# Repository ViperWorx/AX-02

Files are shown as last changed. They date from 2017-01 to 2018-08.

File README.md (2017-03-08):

<h1>AX-02 Delta 3D Printer</h1>

This is a ground up design of a Delta Kinematic based 3D Printer. The ethos of this printer is to keep costs as low as possible but have a rock solid frame as a base with a large print area.

Usable print area is 300mm diameter with a Z Height of around 200mm. The printer is Smoothieware based using the [Azteeg X5 mini](http://www.panucatt.com/azteeg_X5_mini_reprap_3d_printer_controller_p/ax5mini.htm) by Panucatt Devices, 24 volt electronics with a 230v heated bed

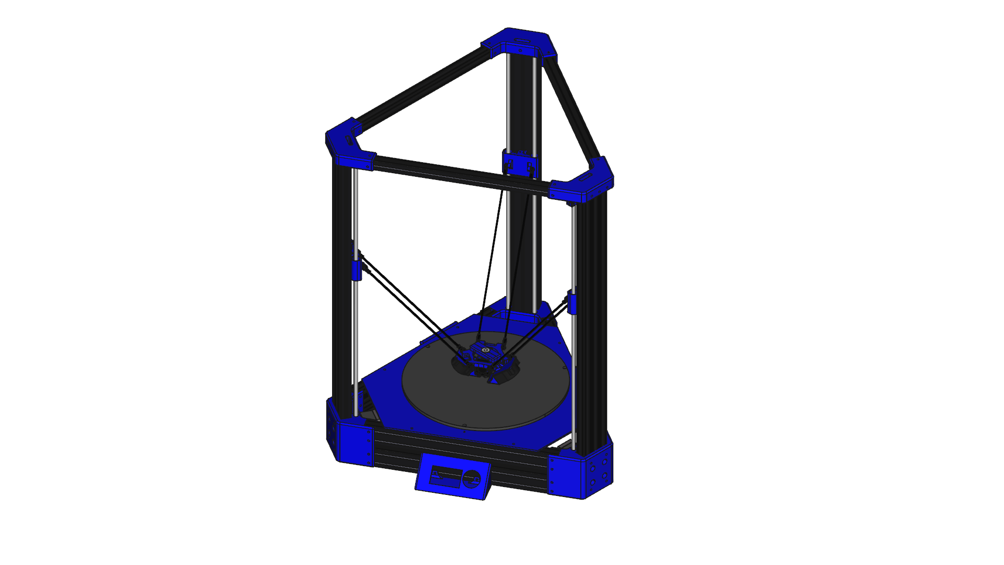
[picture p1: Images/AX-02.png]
 

<hr />
<table border="0px">
<th align="left">
&copy; AxMod 3D Print 2017.
</th>
<tr>
<td>
This documentation describes Open Hardware and is licensed under the CERN OHL v. 1.2.
</td>
</tr>
<tr>
<td>
You may redistribute and modify this documentation under the terms of the
CERN OHL v.1.2. (http://ohwr.org/cernohl). This documentation is distributed
WITHOUT ANY EXPRESS OR IMPLIED WARRANTY, INCLUDING OF
MERCHANTABILITY, SATISFACTORY QUALITY AND FITNESS FOR A
PARTICULAR PURPOSE. Please see the CERN OHL v.1.2 for applicable
conditions
</td>
</tr>
</table>

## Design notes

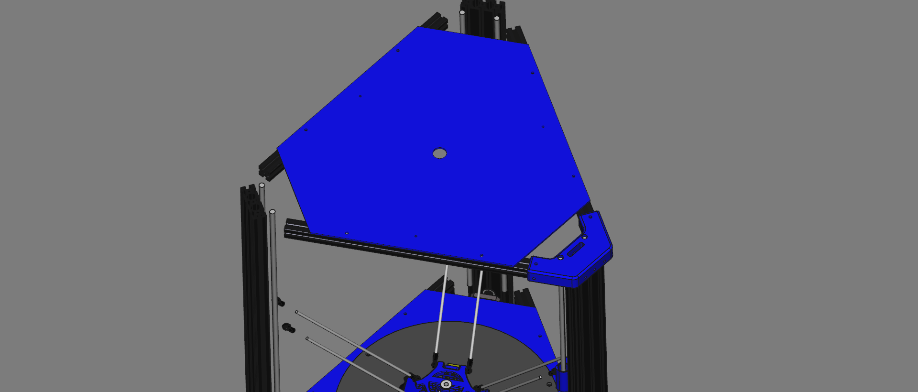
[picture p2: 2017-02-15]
Images/AX-02_5.png

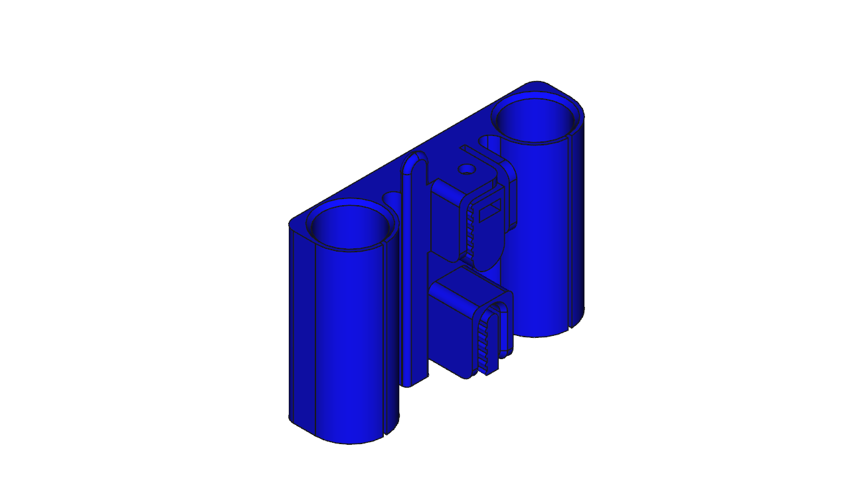
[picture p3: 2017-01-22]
Images/AX-02_3.png

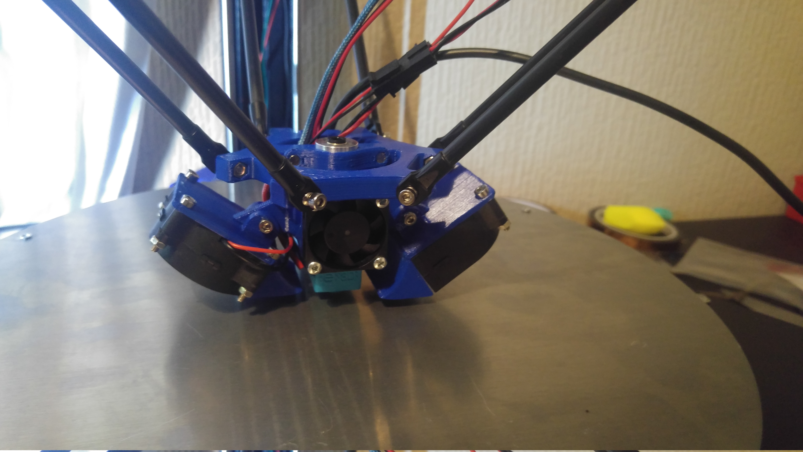
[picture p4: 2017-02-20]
Images/20170220_183212_HDR.jpg

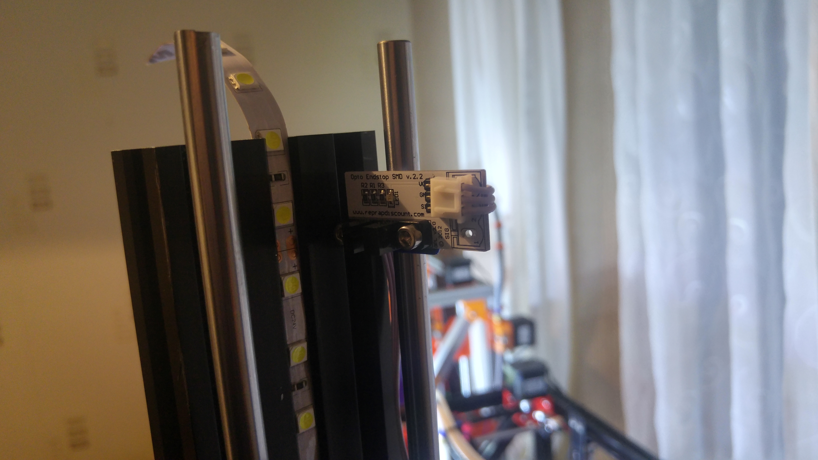
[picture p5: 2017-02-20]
Images/20170220_184052_HDR.jpg

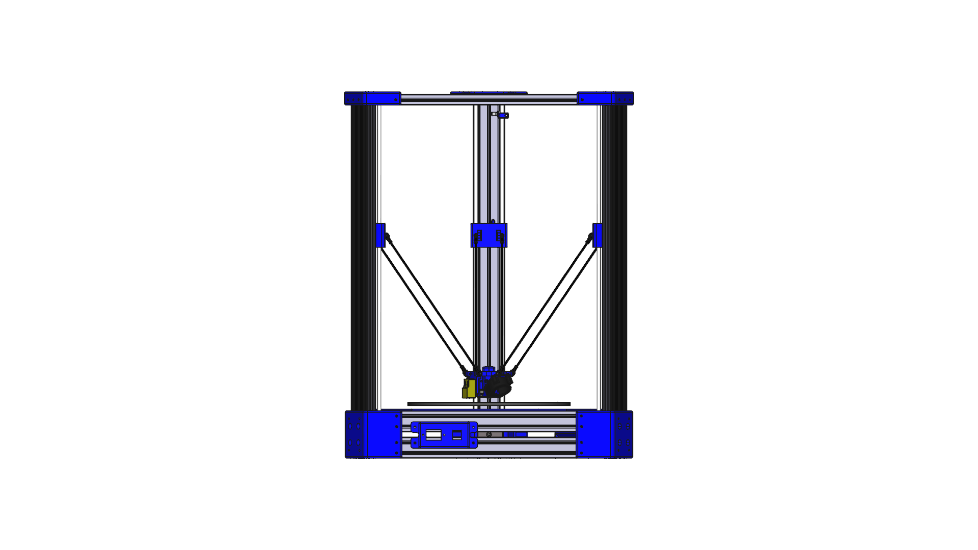
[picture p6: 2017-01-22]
Images/AX-02_1.png

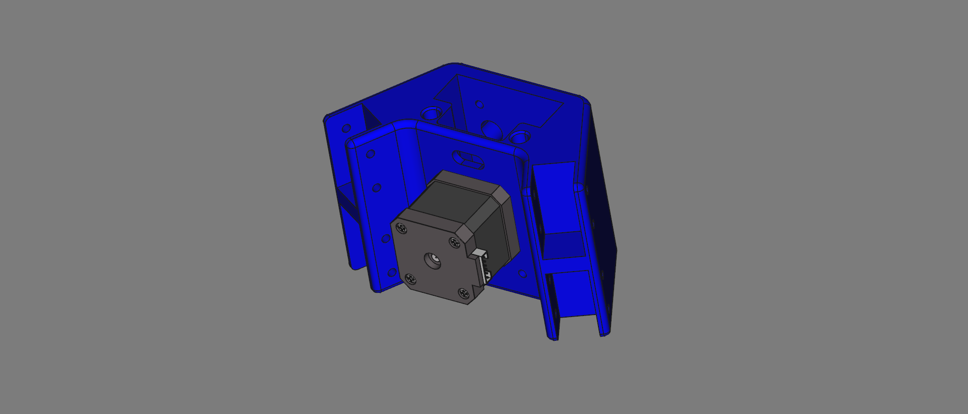
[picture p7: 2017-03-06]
Images/AX-02_6.png

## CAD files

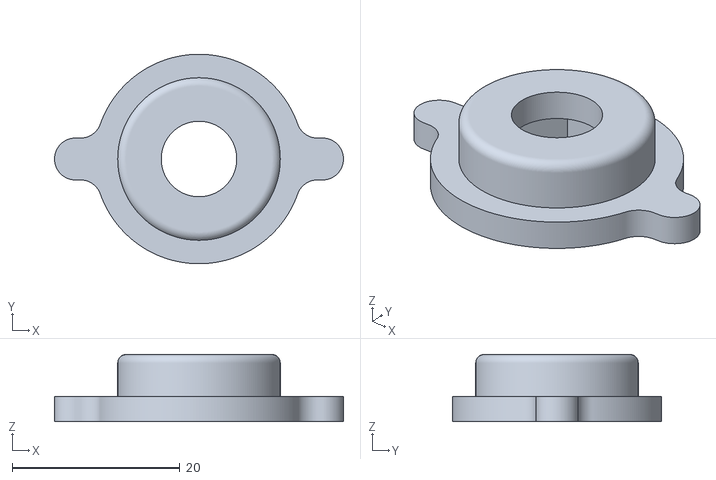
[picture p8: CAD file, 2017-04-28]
1_Spool_Holder_Bottom_Clamp.stl
34.5 x 25.0 x 8.00

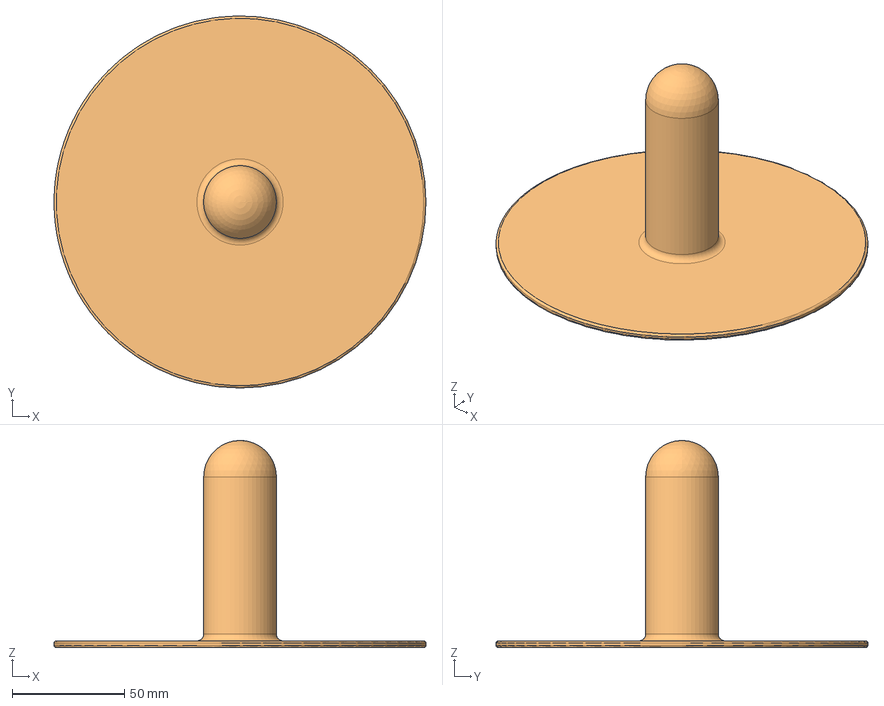
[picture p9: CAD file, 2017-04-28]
FreeCAD/Spool Holder.fcstd
165.6 x 165.6 x 92.2 mm

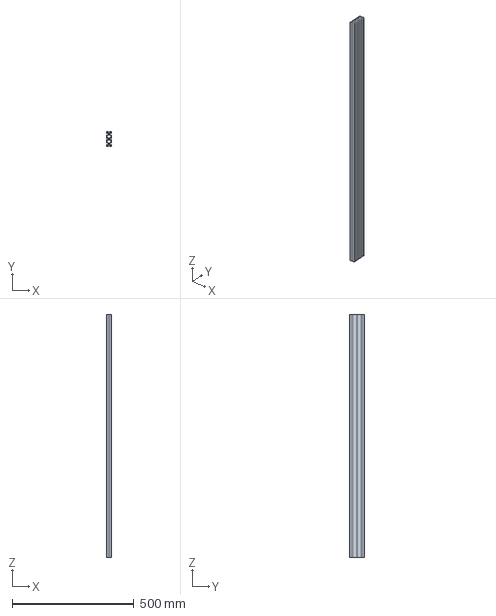
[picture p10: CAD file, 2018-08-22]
FreeCAD/STEP/Hardware Parts/NFS5-2060-1000.stp
20.0 x 60.0 x 1000.0 mm

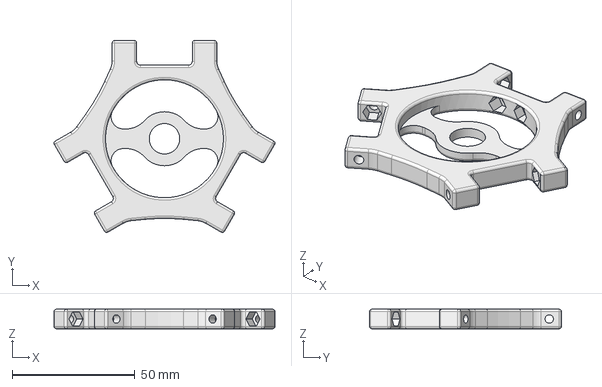
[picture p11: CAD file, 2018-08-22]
FreeCAD/STEP/Printed Parts/Effector_E3D_New.step
89.9 x 78.2 x 8.00 mm

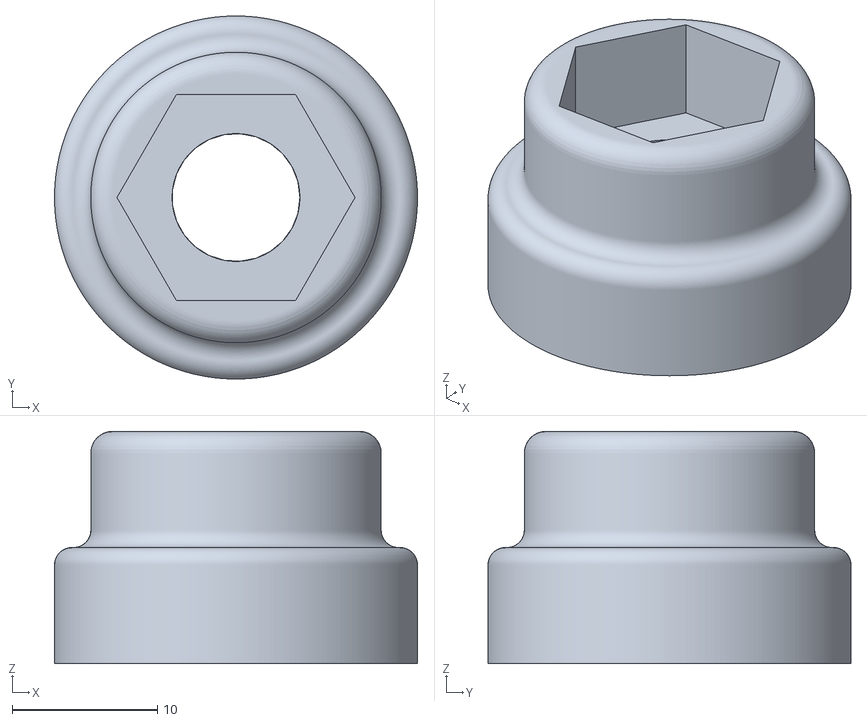
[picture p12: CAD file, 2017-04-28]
1_Spool_Holder_Top_Clamp.stl
25.0 x 25.0 x 16.0

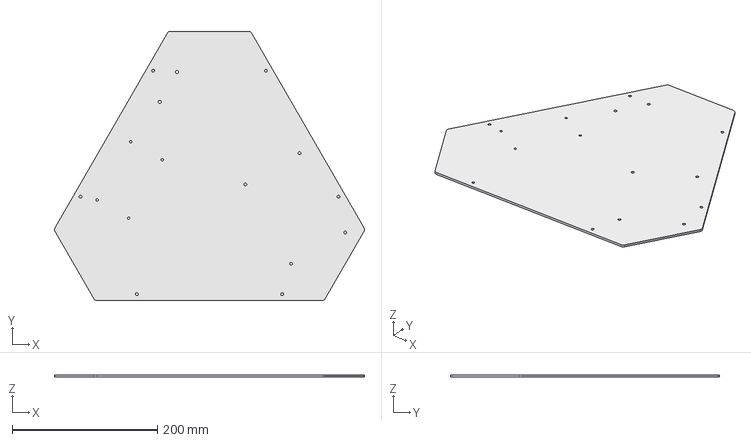
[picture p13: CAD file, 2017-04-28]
FreeCAD/Plates.fcstd
426.4 x 370.7 x 3.00 mm

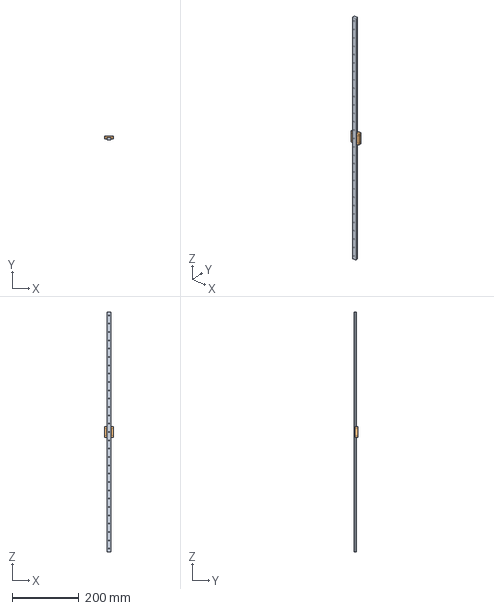
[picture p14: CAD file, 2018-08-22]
FreeCAD/STEP/Hardware Parts/SSEB13-720.stp
27.0 x 13.0 x 720.0 mm
_SSEB13-720_r
_SSEB13_b

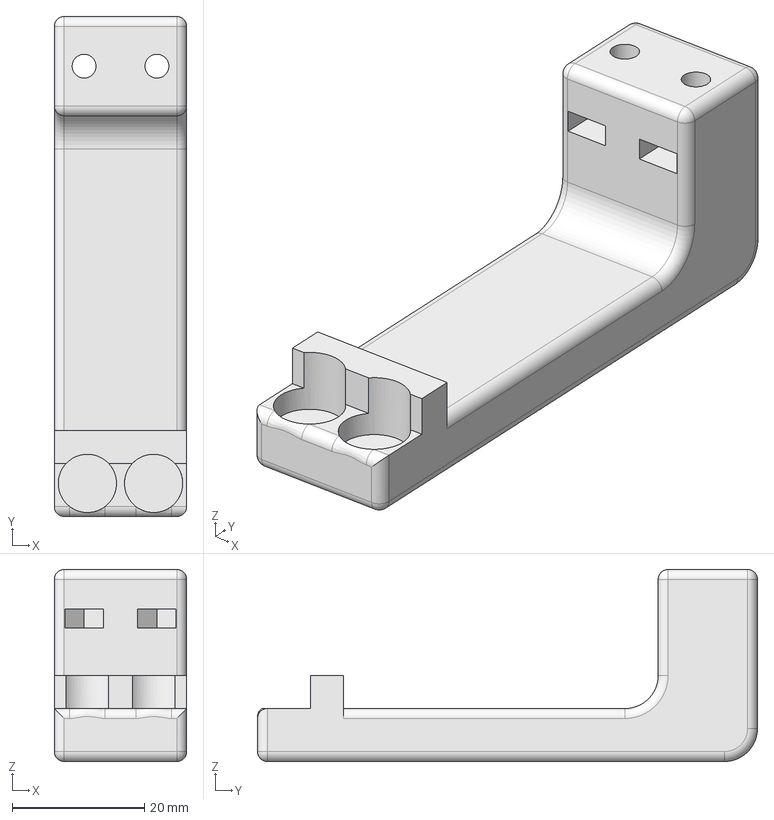
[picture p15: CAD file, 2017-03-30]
FreeCAD/STEP/Printed Parts/Sensor_Mount.step
20.0 x 75.5 x 29.0 mm

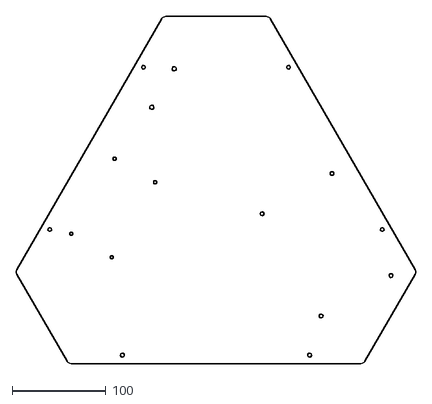
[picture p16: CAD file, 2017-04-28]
Electronics_Plate.dxf
426.9 x 370.7

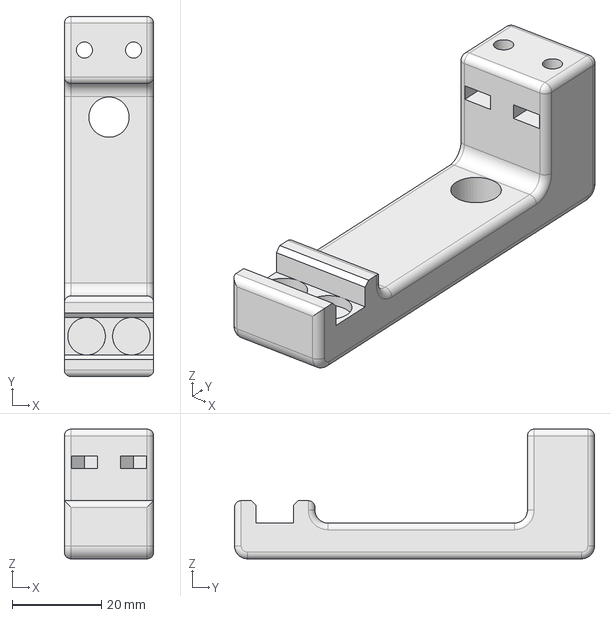
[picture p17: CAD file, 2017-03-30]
FreeCAD/Sensor_Mount.fcstd
20.0 x 80.5 x 29.0 mm

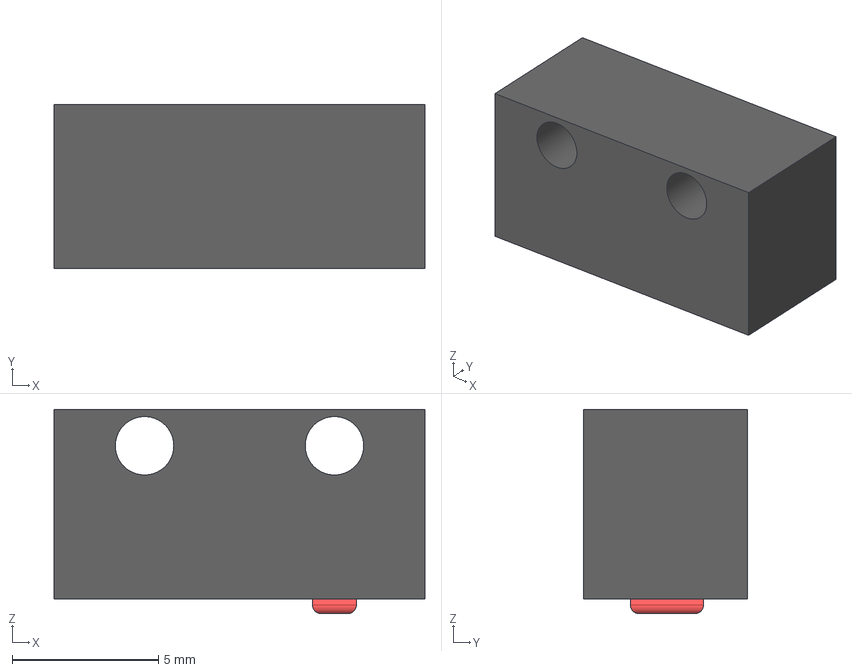
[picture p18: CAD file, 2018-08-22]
FreeCAD/STEP/Hardware Parts/Sub_Micro_Switch_No_Lever.step
12.7 x 5.60 x 7.00 mm
Button

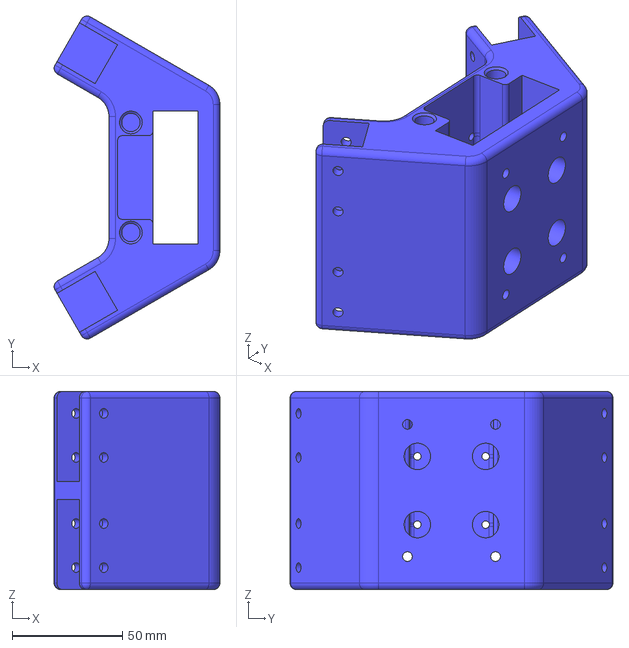
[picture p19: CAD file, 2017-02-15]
FreeCAD/STEP/Printed Parts/Bottom_Bracket.step
75.3 x 146.7 x 90.0 mm

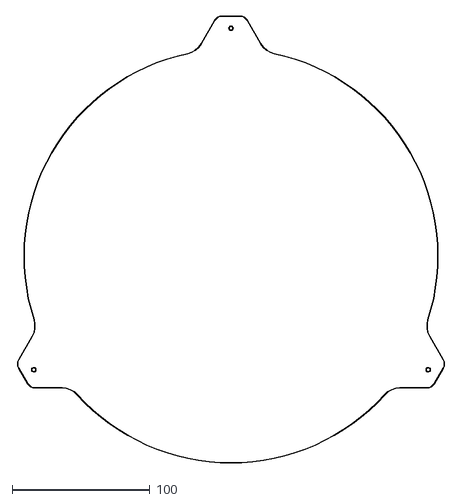
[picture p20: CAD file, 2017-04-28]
Build_Plate.dxf
311.6 x 323.9

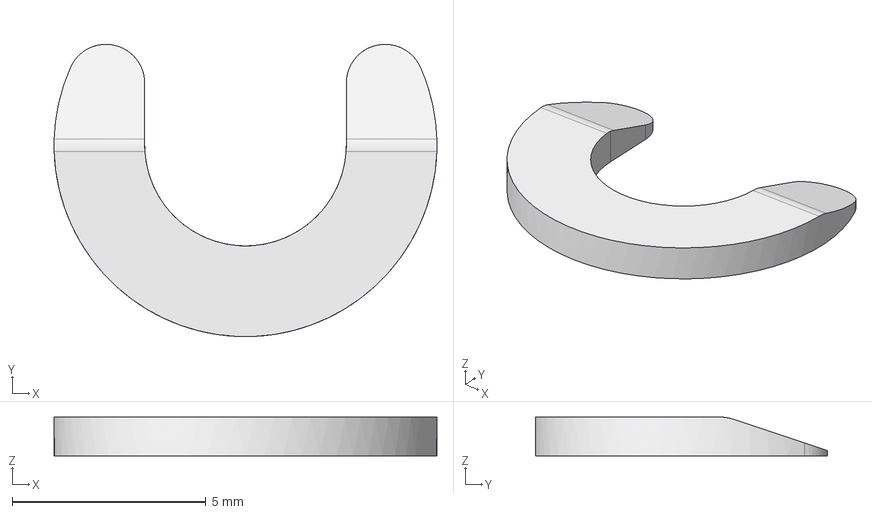
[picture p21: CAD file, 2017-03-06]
FreeCAD/Bowden_Clip.fcstd
9.88 x 7.54 x 1.00 mm

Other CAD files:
FreeCAD/STEP/Hardware Parts/Build_plate.step
FreeCAD/STEP/Printed Parts/Top_Bracket.step
Cover_Plate.dxf
FreeCAD/Arm_Tensioner.fcstd
1_Bowden_Clip.stl
1_Dual_30mm_Fan_Bracket-Board_Cooler.stl
1_Effector.stl
1_Hot_End_Clamp.stl
1_Hot_End_Fan_Housing.stl
1_IEC_Ethernet_USB_Case.stl
1_Mini_Viki_Case_Base.stl
1_Mini_Viki_Case_Front.stl
1_Mini_Viki_Case_Front_Logo.stl
1_Mini_Viki_Case_Front_Logo_Cutout.stl
1_Sensor_Mount.stl
2_Layer_Fan Mount.stl
3_Arm_Tensioner.stl
3_Belt_Tensioner.stl
3_Bottom_Bracket.stl
3_Carriage.stl
3_Endstop_Mount.stl
3_Top_Bracket.stl
6_11mm_Wire_Bundle_Clip.stl
6_8mm_Bushing_Print_In_Nylon.stl
6_Electronics_Plate_Bracket.stl
8_Bowden_Tube_Wire_Bundle_Clip.stl
AX-02_Logo.dxf
FreeCAD/8mm_Bush.fcstd
FreeCAD/AX-02_Logo_3D.fcstd
FreeCAD/Bowden_Tube_ Wire_Bundle_Clip.fcstd
FreeCAD/Dual_30mm_Fan Bracket.fcstd
FreeCAD/Electronics_Plate_Bracket.fcstd
FreeCAD/IEC case.fcstd
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

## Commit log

2017-01-15 Initial File Commit
    [26054-03.stp, 30mm Fan.step, 40mm_fan.stp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]
2017-01-17 Update CAD
    [Optical endstop v3.step, SN04-N.STEP]
2017-01-17 Add STL Files for Printing
    [1_Effector.stl, 1_Hot_End_Clamp.stl, 1_Hot_End_Fan_Housing.stl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]
2017-01-22 Update Top Bracket to use 7mm width idlers over 625ZZ bearings
    [3_Top_Bracket.stl]
2017-01-22 Adding Drawing of Build Plate for cutting
    [Build Plate.dxf]
2017-01-22 Update Carriage to add belt tensioning system
    [1_Belt_Tensioner.stl, 3_Carriage.stl]
2017-01-22 CAD Updated to reflect changes
2017-01-22 Update CAD and clean up model
2017-01-22 Mounting case for IEC Mains socket and Ethernet Coupler
    [1_IEC_Ethernet_Case.stl, IEC case.fcstd]
2017-01-22 Add Mini Viki Case
    [1_Mini_Viki_Case_Base.stl, 1_Mini_Viki_Case_Front.stl, Mini Viki Screen Mount.fcstd]
2017-01-22 Add DXF for laser cutting of Acrylic cover
    [Acrylic_Cover.dxf]
2017-01-22 Step files of Printed parts to clean up CAD
    [Bottom_Bracket.step, Carriage.step, Endstop_mount.step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]
2017-01-22 File Structure tidy
    [26054-03.stp, 30mm Fan.step, 40mm_fan.stp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]
2017-01-22 Add Schlotzz Extruder
    http://www.thingiverse.com/thing:275593
    [1_Compact_Direct_Drive_Extruder_Idler.stl, 1_Compact_Direct_Drive_Extruder_M4.stl]
2017-01-22 Add Spool Hanger
    [1_Spool_Hanger.stl, Spool_Hanger.fcstd]
2017-01-25 Adding Printed Tools - Rotary Tool Delta Arm Cutting Jig
    Cut arms accurately with a rotary tool
    [Arm Cutting Jig.fcstd, Jig_Arm.stl, Jig_Arm_Clamp.stl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]
2017-01-26 Moving fan mount holes to correct position and adding anti warp support
    [2_Layer_Fan Mount.stl, Layer_Fan.step]
2017-01-26 CAD Update
2017-01-26 Fix fan hole postion and add anti-warp support
    [2_Layer_Fan Mount.stl, Layer_Fan.step]
2017-01-27 Correcting mounting holes in Layer fan mount
    [2_Layer_Fan Mount.stl, Layer_Fan+Mount.step, Layer_Fan_Mount.step]
2017-01-27 New design Effector and Hot End Clamping system
    [1_Effector.stl, 1_Hot_End_Clamp.stl]
2017-01-27 CAD Updated to match recent changers
    Arms are now the correct length, new effector, new hot end clamping system, layer fan mounting holes corrected.
2017-01-27 Orientating parts for printing.
    [1_Belt_Tensioner.stl, 1_Effector.stl, 1_Hot_End_Clamp.stl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]
2017-01-29 Remove fan cut out on effector - no longer needed.
    [1_Effector.stl]
2017-01-30 Increase Bed Plate by 10mm
    [Build Plate.dxf]
2017-01-31 Update Layer Fan and Hot end fan mounts
    [1_Hot_End_Fan_Housing.stl, 2_Layer_Fan Mount.stl, Layer_Fan_Mount.step]
2017-02-03 Missed Layer Fan mount from previous commit
    [2_Layer_Fan Mount.stl]
2017-02-03 Correcting Mini Viki placement in mount
    [1_Mini_Viki_Case_Base.stl, 1_Mini_Viki_Case_Front.stl, Mini Viki Screen Mount.fcstd]
2017-02-03 Add 1mm to Hot end mount
    [1_Effector.stl, 1_Hot_End_Clamp.stl]
2017-02-03 Correct mounting screen points and add logo to case (dual extrusion)
    [1_Mini_Viki_Case_Front.stl, 1_Mini_Viki_Case_Front_Logo.stl, 1_Mini_Viki_Case_Front_Logo_Cutout.stl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]
2017-02-04 Tighten up Groove Mount for Hot End
    [1_Effector.stl, 1_Hot_End_Clamp.stl]
2017-02-05 Changing number to print
    [1_Belt_Tensioner.stl, 3_Belt_Tensioner.stl]
2017-02-05 Modified so rods can be slid into place
    [3_Top_Bracket.stl]
2017-02-05 Tolerances on Groove mount tightened up
    [1_Hot_End_Clamp.stl]
2017-02-05 CAD File updated with changes
2017-02-05 Correct error with Belt tensioning system
    [3_Belt_Tensioner.stl, 3_Carriage.stl]
2017-02-05 Reduce Endstop mounting pad by 1.5mm
    Allow for belt path
    [3_Endstop_Mount.stl]
2017-02-05 Main CAD File updated to reflect changes
2017-02-06 Re-work GT2 belt tensioner
    [3_Belt_Tensioner.stl, 3_Carriage.stl]
2017-02-08 IEC case.. now with added USB hole..
    [1_IEC_Ethernet_Case.stl, 1_IEC_Ethernet_USB_Case.stl, IEC case.fcstd]
2017-02-09 Add Acrylic Electronics mounting plate
    [Electronics_Plate.dxf]
2017-02-15 Add 8mm Bushings to be printed in Nylon
    [6_8mm_Bushing_Print_In_Nylon.stl, 8mm_Bush.fcstd]
2017-02-15 Add extra STEP files for modelling
    [2020_1.step, 2040_1.obj, 2040_1.step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]
2017-02-15 Update main CAD
2017-02-15 Add .gitignore - remove tools as design did not work well
    [Arm Cutting Jig.fcstd, Jig_Arm.stl, Jig_Arm_Clamp.stl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]
2017-02-20 Enlarge idler hole
    [3_Top_Bracket.stl]
2017-02-20 Add Cover Step file
    [Cover.step]
2017-02-21 Add wire routing hole
    [3_Bottom_Bracket.stl]
2017-02-21 Enlarge rod holes
    [3_Top_Bracket.stl]
2017-02-21 CAD Updated with latest changes
2017-02-23 Adding material to carraige to prevent snapping
    [3_Carriage.stl]
2017-02-23 Adding Active Board cooling bracket
    [1_Dual_30mm_Fan_Bracket-Board_Cooler.stl, Dual_30mm_Fan Bracket.fcstd]
2017-02-25 Wire Management parts added
    [Bowden_Tube_ Wire_Bundle_Clip.fcstd, Wire_Bundle_Clip.fcstd]
2017-03-06 Add Electronics Plate Bracket
    [6_Electronics_Plate_Bracket.stl, Electronics_Plate_Bracket.fcstd]
2017-03-06 Add Arm Tensioners
    [3_Arm_Tensioner.stl, Arm_Tensioner.fcstd]
2017-03-06 Main CAD Update
2017-03-06 Modify hole Position in electronics plate
    [Electronics_Cover.step, Electronics_Plate.dxf]
2017-03-06 Add Bowden Clip
    [1_Bowden_Clip.stl, Bowden_Clip.fcstd]
2017-03-06 Add Bottom Corner render - added wire channel
2017-03-14 Remove Schlotzz Extruder - Add Drakon Extruder
    [1_Compact_Direct_Drive_Extruder_Idler.stl, 1_Compact_Direct_Drive_Extruder_M4.stl]
2017-03-30 New Effector/Sensor mount
    Sensor mount is now detachable and is positioned under the nozzle
    [1_Effector.stl, 1_Sensor_Mount.stl, Sensor_Mount.fcstd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]
2017-04-28 Rework Plates for better fit
    New Build Plate
    Cover Plate adjusted to fit better
    Electronics plate totally reworked as it was way out and only just fit
    [Acrylic_Cover.dxf, Build Plate.dxf, Build_Plate.dxf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]
2017-04-28 Internal file rename
    [Build_plate.step, Plates.fcstd]
2017-04-28 Add new Spool holder, remove old hanger
    [1_Spool_Hanger.stl, 1_Spool_Holder_Bottom_Clamp.stl, 1_Spool_Holder_Top_Clamp.stl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]
2017-05-14 Update Drakon to Current commit
2018-08-22 Add new Reference parts
    [Effector_E3D_New.step, NFS5-2060-1000.stp, SSEB13-720.stp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]
